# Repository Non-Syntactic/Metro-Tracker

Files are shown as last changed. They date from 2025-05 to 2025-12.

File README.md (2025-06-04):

# Metro Tracker

The Seaford Metro Tracker is an IOT (Internet of Things) device powered by a tiny esp32 that processes publicly available GPS Adelaide metro data from the internet and plots it into RGB lights. It does this with it’s built in Wi-Fi antenna, connecting to an access point where it can query the API (application programming interface). It shows train stations between Hallet Cove beach, to the Adelaide City station. 

Each train picked up by the tracker is given a different colour to help identify them on the canvas. As the trains move along the railway, the brightness for the LEDs around it change based on the distance. The indicator light will turn green when pulling down data, which can take up to 10 seconds because of its primitive Wi-Fi power. The Metro Tracker is a really cool installation, where art meets technology.  It makes a great feature to hang on any wall if you don’t mind the bandwidth it uses. 

## Info
### Quick Information
Here's a link to the API route: http://gtfs.adelaidemetro.com.au/v1/realtime/vehicle_positions/debug

|  |  |
|--|--|
|Platform|Arduino|
|Language|C++|
|Board|ESP32-S3 Supermini|
|IDE|Platform IO|

### Code Breakdown
To draw the trains on the LED lights is a 2 step process:
1. Fetch the Adelaide Metro API, and parse it character by character extracting usefull data
2. Map the coordinates from the API into the LED lights on the canvas.

Fetching data from the internet is simple on an ESP32: Contact the server -> Store the output in a `String` variable. Unfortunately, `HTTPClient` struggles when writing the entire output from the api into a string. Its not strictly that the ESP doesn't have enough memory space to store the output, but http client doesn't like it when you try to store 218236 characters into a single variable..
So instead of writing the output to a variable, the API is parsed character by character to extract the data from it.

So what does the reply from the server look like?
```
header { // Header that occurs only at the start
  gtfs_realtime_version: "1.0"
  incrementality: FULL_DATASET
  timestamp: 1743992197
}
entity { // Entity contains data about the vehicle
  id: "V10233231002"
  vehicle {
    trip {
      trip_id: "1023323"
      start_date: "20250407"
      schedule_relationship: SCHEDULED
      route_id: "167C" // This is what we are interested in
      direction_id: 1
    }
    position {
      latitude: -34.9487 // And these ones
      longitude: 138.5626 // ^^
      bearing: 291.24
      speed: 2.7
    }
    timestamp: 1743992185
    vehicle {
      id: "1002"
      label: "1002"
      [transit_realtime.tfnsw_vehicle_descriptor] {
        air_conditioned: true
        wheelchair_accessible: 1
      }
    }
  }
}
entity { etc...
```
Umm, what? For some reason, the API is not any sort of *well known* markup language like JSON or XML but instead, although looking quite similar to JSON. Attempting to parse it as JSON doesn't work from several inconsistencies in the data. What the ESP has to do is check each character for token seperating symbols (`"`,`:`) and grab the data that lies next to them. Not too hard but kind of a pain.

To display the parsed long and lat, the tracker has a list of stops (one for each light) that it uses to calculate a brightness factor for each. Stops are defined in a struct:
```cpp
struct Stops {
  double lon;
  double lat;
  int index;
  String stop_name;

  Stops(double a, double b, double c, String d) : lon(a), lat(b), index(c), stop_name(d) {}
};
```
..and defined in an array called `STOPS`:
```cpp
const Stops STOPS[] = {
  Stops(-35.0795155,138.5020983,0,"Hallet Cove Beach"),
  Stops(-35.0659680,138.5056141,1,"Hallet Cove"),
  Stops(-35.0462356,138.5126078,2,"Marino Rocks"),
  etc..
```
Once fresh data has been extracted, the tracker runs through it's list of stops, and then through a list of found trains and calculates an LED brightness for each light in the track based on the distance. Distance is determined using standard distance formula:
```cpp
dist = sqrt(pow((train.lon-stop.lon),2)+pow((train.lat-stop.lat),2))*DISTANCE_MUL;
```
..Multiplied by an additional variable to adjust the range.
### Other
- 3D models are made in OpenSCAD, a programing CAD software.

## Todo
- Clean up `trackerTool.py`
- Add images to the repo
- Better logging for `code/src/main.cpp`

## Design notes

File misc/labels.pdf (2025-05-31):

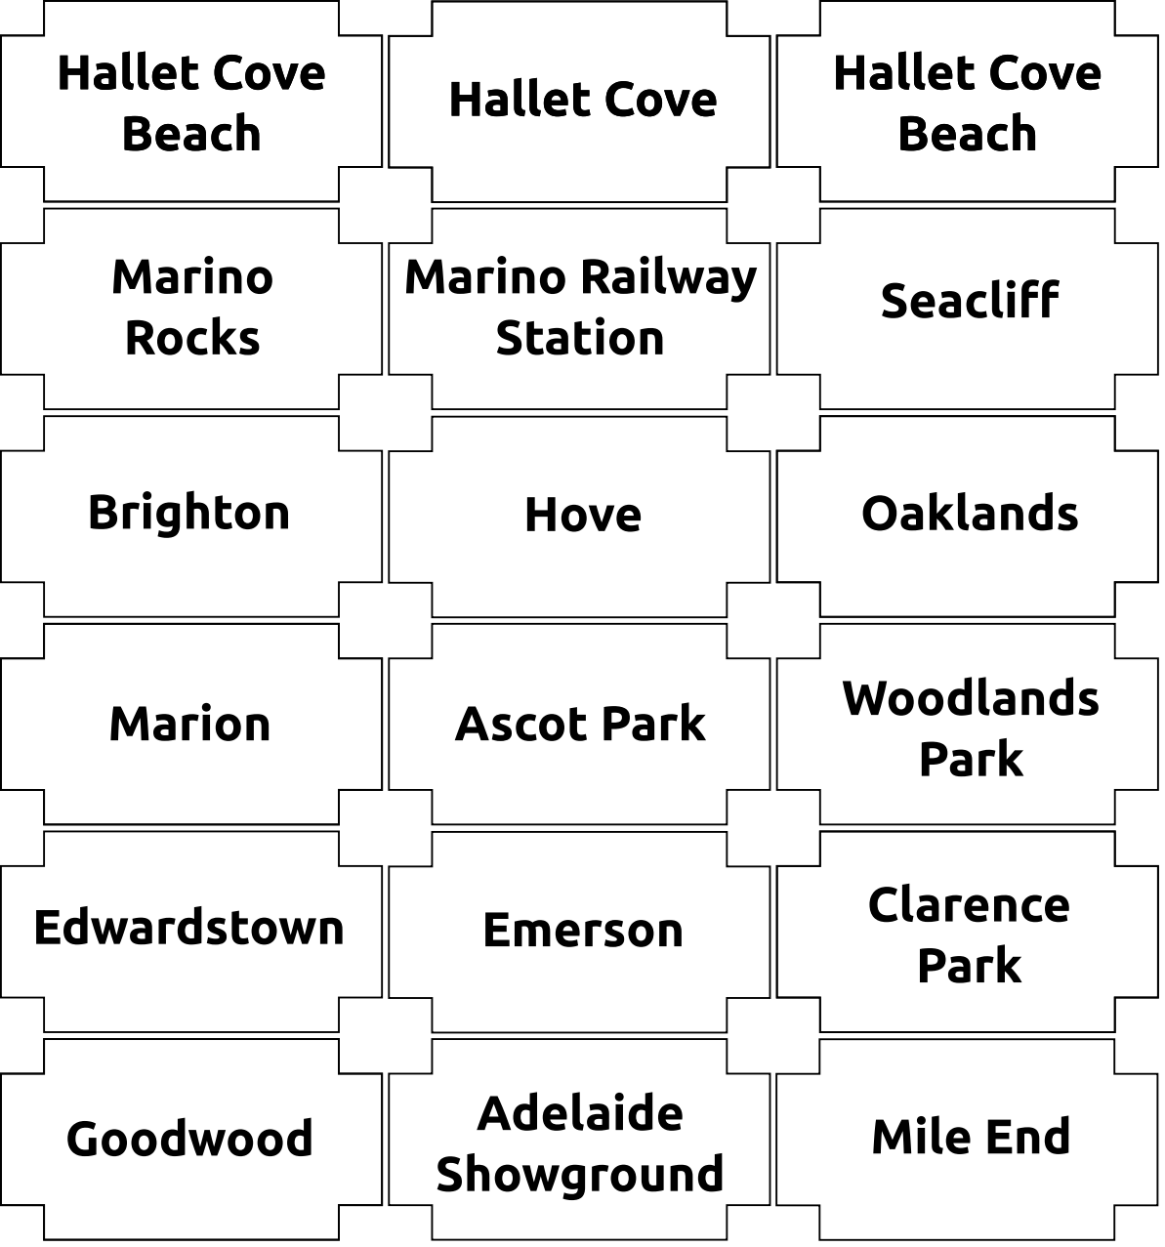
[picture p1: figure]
Hallet Cove; Beach; Marino Railway Station; Marino Rocks; Seacliff; Brighton; Marion; Hove; Ascot Park; Oaklands; Woodlands Park; Edwardstown; Goodwood; Emerson; Adelaide Showground; Clarence Park; Mile End

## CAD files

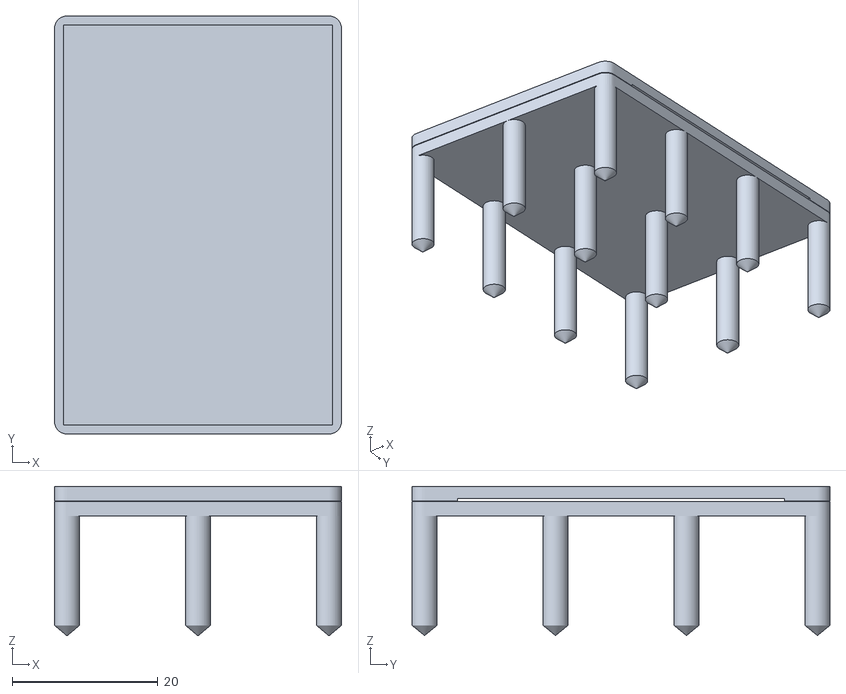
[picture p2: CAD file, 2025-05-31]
3DModels/stl/labelUnit-large.stl
39.5 x 57.5 x 20.5

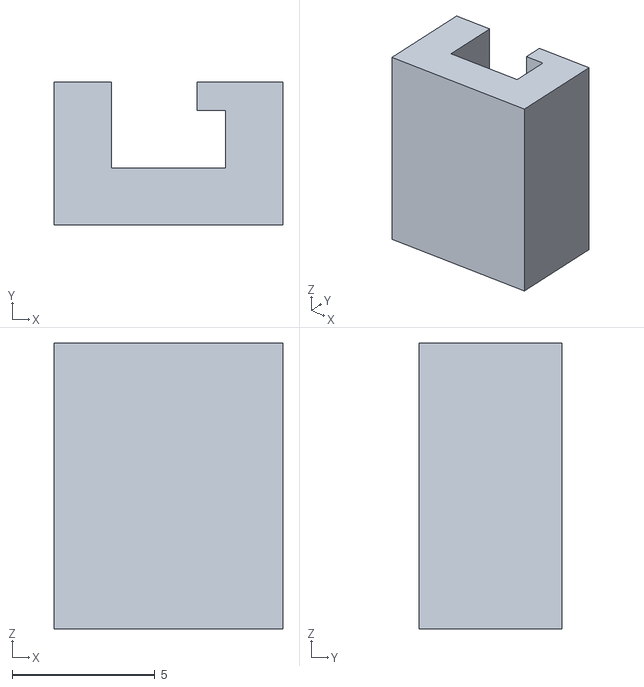
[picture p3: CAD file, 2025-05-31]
3DModels/stl/labelClip.stl
8.00 x 5.00 x 10.0

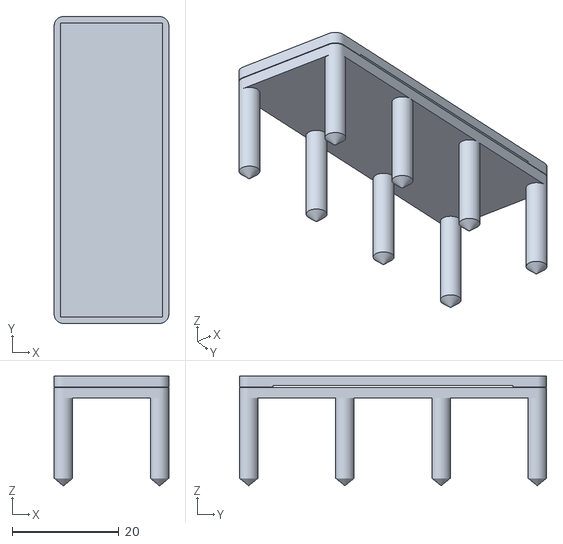
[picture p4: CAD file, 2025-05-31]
3DModels/stl/labelUnit.stl
21.5 x 57.5 x 20.5

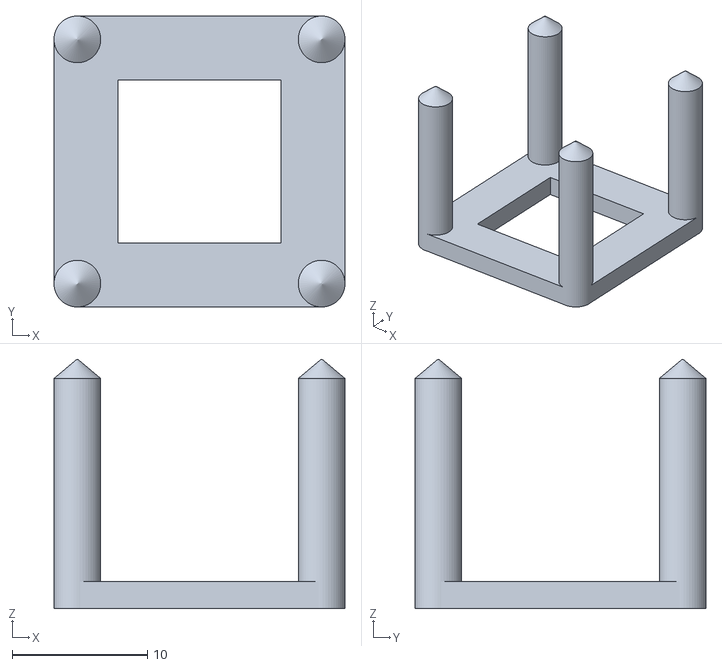
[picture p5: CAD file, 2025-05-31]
3DModels/stl/ledUnit.stl
21.5 x 21.5 x 18.4

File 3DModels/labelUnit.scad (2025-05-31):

$fn=50;
D=3.45;
H=15;
G=18;
lw=45;

X=3;
Y=4;

label();
translate([+14,-4,13])rotate([0,-90]) !clip();

module clip() {
    a=4;
    linear_extrude(10)
    difference() {
        square([a*2,5]);
        translate([a/2,2]) square([a,2.0]);
        translate([a/2,2]) square([3,6]);
    }
    
}

module label() {

    union() {
        for(x=[0:X-1],y=[0:Y-1]) translate([x*G,y*G])
        union() hull() {  
            cylinder(h=H+2,d=D);
            rotate([45,0]) cube([0.1,2,2],center=true);
        }
            
        translate([0,0,H])
        linear_extrude(2)
        offset(D/2) square([G*(X-1),G*(Y-1)]);
    }
        
    translate([0,0,H+2.1])
    difference() {
        linear_extrude(2)
        offset(D/2) square([G*(X-1),G*(Y-1)]);
        
        linear_extrude(5,center=true)
        offset(delta=0.5) square([G*(X-1),G*(Y-1)]);
        
        translate([-5/2,G*(Y-1)/2-lw/2,-4.7]) cube([G*(X-1)+lw,lw,5]);
    }

}

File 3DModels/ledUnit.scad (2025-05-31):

$fn=50;
D=3.45;
H=15;
R=25.5;

unit();

module unit() rotate([0,180,45]) {
    for(i=[0:3]) rotate([0,0,i*90]) translate([R/2,0])
        union() hull() {  
            cylinder(h=H+2,d=D);
            rotate([45,0]) cube([0.1,2,2],center=true);
          
        }
        
    translate([0,0,H])
    rotate([0,0,45]) linear_extrude(2)
    difference() {
        offset(D/2) square(18,center=true);
        square(12,center=true);
    }
}

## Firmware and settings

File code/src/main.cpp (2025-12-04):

/*
Use the following bash to get the length of the return data:
`wget http://gtfs.adelaidemetro.com.au/v1/realtime/vehicle_positions/debug -o /dev/null -O /tmp/apilen;a=$(cat /tmp/apilen);echo ${#a};rm /tmp/apilen`
*/

// TODO: Change this
#ifdef DEVELOPMENT_MODE
  #define DEBUG true
#else
  #define DEBUG true
#endif

// Include packages
#include <Arduino.h>
#include <vector>
#include <iomanip>
#include <FastLED.h>
#include <WiFi.h>
#include <HTTPClient.h> // For API requesting

/// The API route to get train data
const char API[] = "http://gtfs.adelaidemetro.com.au/v1/realtime/vehicle_positions/debug";

const int LAT_RANGE = 1000;
const int LON_RANGE = 1000;

HTTPClient http; // Create the http client object

//// Setup LEDS
#define NUM_LEDS 19
#define DATA_PIN 3
#define DEBUG_LED 18
CRGB leds[NUM_LEDS];

struct Stops {
  double lon;
  double lat;
  int index;
  String stop_name;

  Stops(double a, double b, double c, String d) : lon(a), lat(b), index(c), stop_name(d) {}
};

/* ---- CONFIG ---- */

// Train stops for each LED
const Stops STOPS[] = {
  Stops(-35.0795155,138.5020983,0,"Hallet Cove Beach"),
  Stops(-35.0659680,138.5056141,1,"Hallet Cove"),
  Stops(-35.0462356,138.5126078,2,"Marino Rocks"),
  Stops(-35.0422496,138.5172564,3,"Marino Railway Station"),
  Stops(-35.0324786,138.5212542,4,"Seacliff"),
  Stops(-35.0216526,138.5192003,5,"Brighton"),
  Stops(-35.0122889,138.5236356,6,"Hove"),
  Stops(-35.0091272,138.5408492,7,"Oaklands"),
  Stops(-34.9990117,138.5526242,8,"Marion"),
  Stops(-34.9906526,138.5604201,9,"Ascot Park"),
  /*INTERSECTION*/
  Stops(-34.9821925,138.5673640,10,"Woodlands Park"),
  Stops(-34.9720174,138.5712942,11,"Edwardstown"),
  Stops(-34.9667332,138.5734255,12,"Emerson"),
  Stops(-34.9720174,138.5712942,13,"Clarence Park"),
  Stops(-34.9513205,138.5850539,14,"Goodwood"),
  Stops(-34.9439191,138.5831178,15,"Adelaide Showground"),
  Stops(-34.9251956,138.5800757,16,"Mile End"),
};

// The Route IDs to be tracked
const String TRACKED_ROUTES[] = {"SEAFRD","FLNDRS"};

#define REFRESH_RATE 40000 // Delay in milliseconds until the board refreashes
#define DISTANCE_MUL 20000 // Controls the *spread* of brightness for LEDs around the train

#define CORE_DEBUG_LEVEL = 5

// Configuring WiFi auth
const char WIFI_SSID[] = "WIFI_SSID";
const char WIFI_PASSWORD[] = "WIFI_PASSWORD";

/* ---- END CONFIG ---- */


void setup() {
  // Attach LEDS
  FastLED.addLeds<WS2811, DATA_PIN>(leds, NUM_LEDS);
  
  Serial.begin(115200);
  pinMode(LED_BUILTIN,OUTPUT);

  for (int i=0;i<NUM_LEDS;i++) leds[i].setRGB(25,25,25);

  // Connect to WiFi
  Serial.println("[INFO] : (setup) Connecting to AP...");  

  leds[DEBUG_LED] = CRGB::Yellow; FastLED.show();

  WiFi.begin(WIFI_SSID, WIFI_PASSWORD);
  while(WiFi.status() != WL_CONNECTED) {
    delay(500);
  }

  Serial.print("[INFO] : (setup) Connected to AP! IP is: ");
  Serial.println(WiFi.localIP());
  leds[DEBUG_LED] = CRGB::Cyan; FastLED.show();
}

struct Coords {
  double lon;
  double lat;
  String route;

  Coords(double a, double b, String c) : lon(a), lat(b), route(c) {}
};


// Converts lon and lat into 0-500 & 0-1000 range
void convertCoords(Coords &coords) {
  coords.lon = (coords.lon+180)/360*LON_RANGE;
  coords.lat = (coords.lat+180)/360*LAT_RANGE;
}

void printLog(uint8_t indent, String type, String origin, String message) {
  if (type == "DEBUG" && !DEBUG) return;

  String indentString;
  for (int i=0;i<indent*2;i++) indentString += " ";

  Serial.println(indentString+"["+type+"] : ("+origin+")  "+message);
}

// Method to get the position of the trains
std::vector<Coords> getTrainData() {
  printLog(0,"DEBUG","getTrainData","Fetching API...");

  std::vector<Coords> locations;
  
  http.begin(API);
  int status_code = http.GET();

  if (status_code > 0 && status_code == HTTP_CODE_OK) {
    printLog(0,"DEBUG","getTrainData","Request 200 OK. Passing data");
    leds[DEBUG_LED] = CRGB::Green; FastLED.show();


    WiFiClient *stream_pointer = http.getStreamPtr();
    
    //int locations_set = 0; // How many locations have been set in `locations[][]`

    String route_id = "";
    double route_lon = 0;
    double route_lat = 0;

    String data_key;
    String data_value;
    char c;
    int j=0;

    //stream_pointer->available()
    delay(1000);
    int response_size = http.getSize();
    while (stream_pointer->available() > 30) {
      while (stream_pointer->available() < 3000 && response_size-j > 3000) {
        delay(1);
      }

      //// Get the data key
      while (c != ':') {
        j++;
        c = stream_pointer->read();
        if (c != ' ') {
          data_key += c;
        }
      }

      //// Get the data value
      while (c != '\n') {
        j++;
        c = stream_pointer->read();
         if (c != ' ') {
          data_value += c;
        }
      }

      //Serial.print(stream_pointer->available());
      //Serial.print(" ");
      //Serial.println(j);

      //// Clean the data and remove any yucky characters
      /// NOTE: The parsing isnt perfect but its good enough (:
      int clean_index = data_key.lastIndexOf("{\n");
      if (clean_index >= 0) {
        data_key = data_key.substring(clean_index+2,-1);
      }

      /// Remove the newline
      data_value.remove(data_value.length()-1,1);

      /// Remove `"` from a string value if present
      if (data_value.indexOf('"') >= 0) {
        data_value.remove(0,1);
        data_value.remove(data_value.length()-1,1);
      }

      //// Now check if the data is actully needed and set the variables if so
      /// Set the route_id if it is in the lists
      if (data_key == "route_id:") {
        for (String route : TRACKED_ROUTES) {
          if (data_value == route) {
            route_id = data_value;
            printLog(1,"DEBUG","getTrainData","Found route "+route_id);
          }
        }
      }
      else if (data_key == "latitude:" && route_id != "") {
        route_lat = std::stod(data_value.c_str());
        printLog(1,"DEBUG","getTrainData","  Found lat "+String(route_lat));
      }
      else if (data_key == "longitude:" && route_id != "") {
        route_lon = std::stod(data_value.c_str());
        printLog(1,"DEBUG","getTrainData","  Found lon "+String(route_lon));
      }

      //// Add to locations if all variables have value
      if (route_lon && route_lat && route_id) {
        printLog(1,"DEBUG","getTrainData","  Appended to locations");
        locations.push_back(Coords(route_lat,route_lon,route_id));

        /// Reset route variables
        route_id = "";
        route_lon = 0;
        route_lat = 0;
      }

      /// Reset data variables
      data_key = "";
      data_value = "";
    }
    http.end();

        
    printLog(0,"DEBUG","getTrainData","Parsing done!");

    return locations;
  }
  else {
    printLog(0,"ERROR","getTrainData","Could not fetch data successfully! Error code: "+String(status_code));

    leds[DEBUG_LED] = CRGB::Red; FastLED.show();

    return locations;
  }
}

void showLights(std::vector<Coords> trains) {
  double latDist, lonDist;
  long stopBrightness;
  printLog(0,"DEBUG","showLights","Showing lights");

  for (int i=0;i<NUM_LEDS;i++) leds[i].setRGB(0,0,0);
  leds[DEBUG_LED].setRGB(0,0,0);

  int trainNo = 0;
  double dist = 0;

  for (Stops stop : STOPS) {
    for (Coords train : trains) {
      dist = sqrt(pow((train.lon-stop.lon),2)+pow((train.lat-stop.lat),2))*DISTANCE_MUL;

      stopBrightness = 255 - dist;
      
      if (stopBrightness > 0) {
        CRGB oldStop = leds[stop.index];
        CRGB newStop;

        newStop.setHSV(trainNo*2,255,stopBrightness);
        //newStop.setHSV(map(trainNo,0,trains.size(),0,85),255,stopBrightness);

        // Colour mixing
        leds[stop.index].setRGB(
          (newStop.r+oldStop.r)/2,
          (newStop.g+oldStop.g)/2,
          (newStop.b+oldStop.b)/2
        );
        
        ESP_LOGD("showLights", "Writing to led: %d => %d",stop.index,stopBrightness);
      }

      trainNo++;
    }
  }
  FastLED.show();
}


void loop() {
  std::vector<Coords> trains = getTrainData();

  showLights(trains);

  delay(REFRESH_RATE);
}
